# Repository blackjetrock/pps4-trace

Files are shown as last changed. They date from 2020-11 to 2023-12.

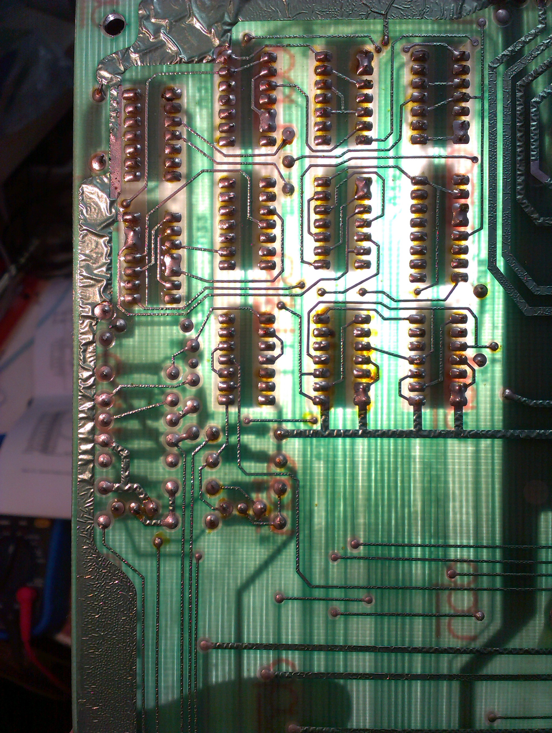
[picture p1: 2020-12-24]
schematics/IMAG7078.jpg

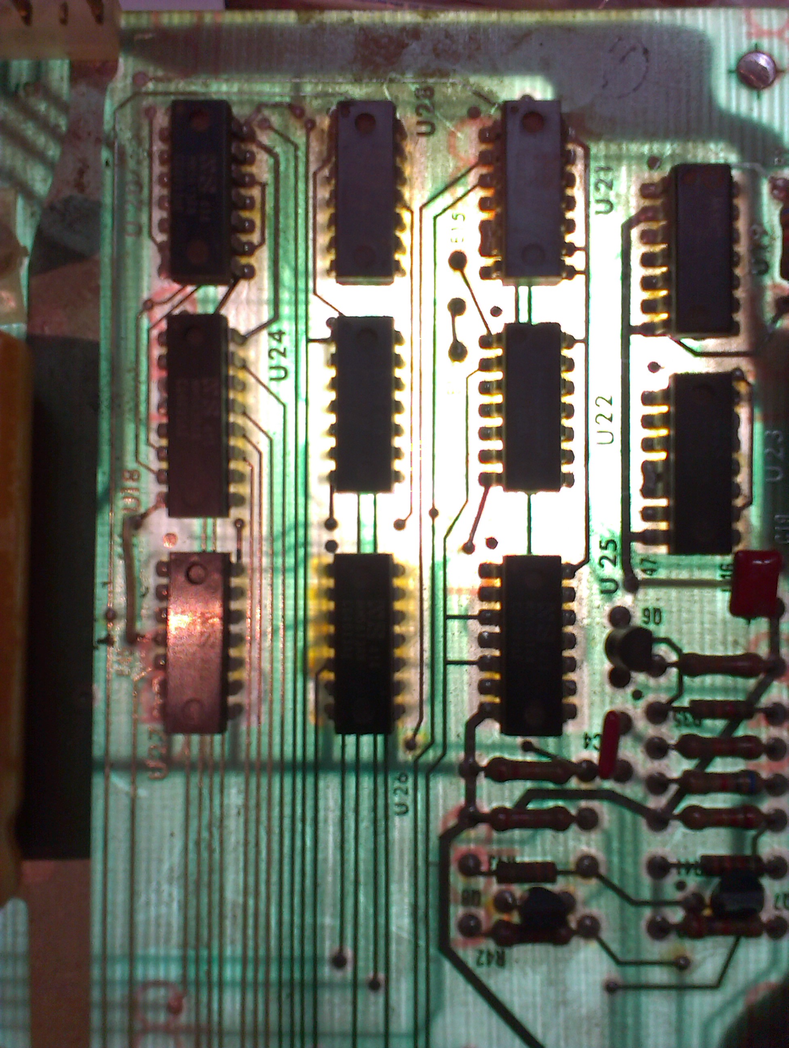
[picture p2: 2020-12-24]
schematics/IMAG7074.jpg

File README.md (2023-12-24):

# pps4-trace

Circuit to attempt to trace the address and data busses of the PPS-4 processor. the aim is to capture the ROM contents by sniffing the bus.
PPS-4 runs on -17V so circuit sits on 0V to -17v and divides down the inputs to 3V3.
PSU runs off PPS-4 supply

There's a few ROM image files I've managed to capture.

Although the bus tracing worked, it was difficult to work out exactly which ROM was bank switched and when. I therefore built a ROM dumper, desoldered a set of ROMs from a 920 and dumped them. This gave me the bank switching regime as the ROMs only responded to certain addressing. These ROMs were concatenated, effectively, and can be run in the simulator.
Details of the bank switching are in the simulator ROM file.

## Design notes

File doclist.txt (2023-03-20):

Part numbers of documents

Wanted

Programmer's Reference Manual        P/N 29001N20
Programmers' Ref Manual Supp No 1    P/N 29001N21

Already got copy

PPS-4 Basic devices Data Sheet       29003N11
PPS-4 Basic devices Supplement       2519-D-13
Bus Interface Circuit                10738N11

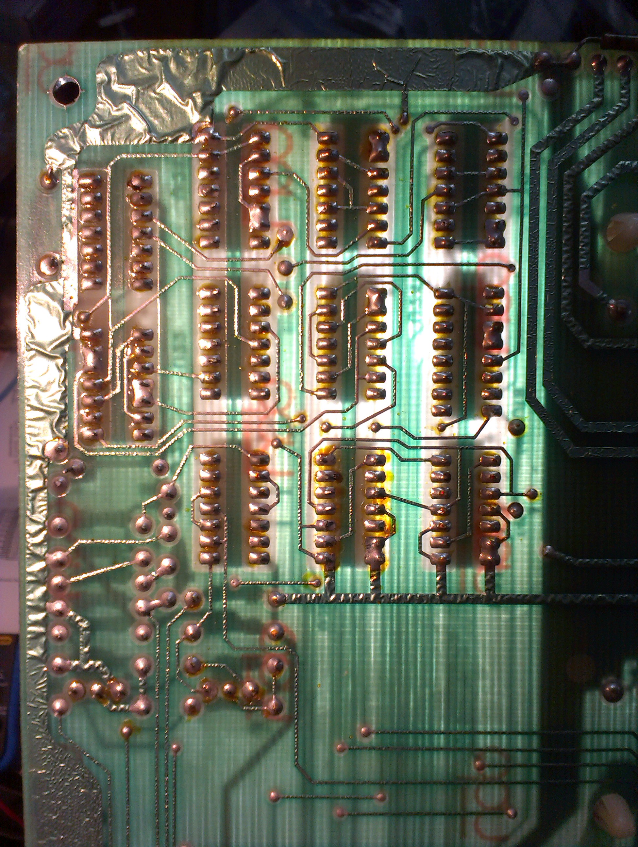
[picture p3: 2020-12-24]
schematics/IMAG7080.jpg

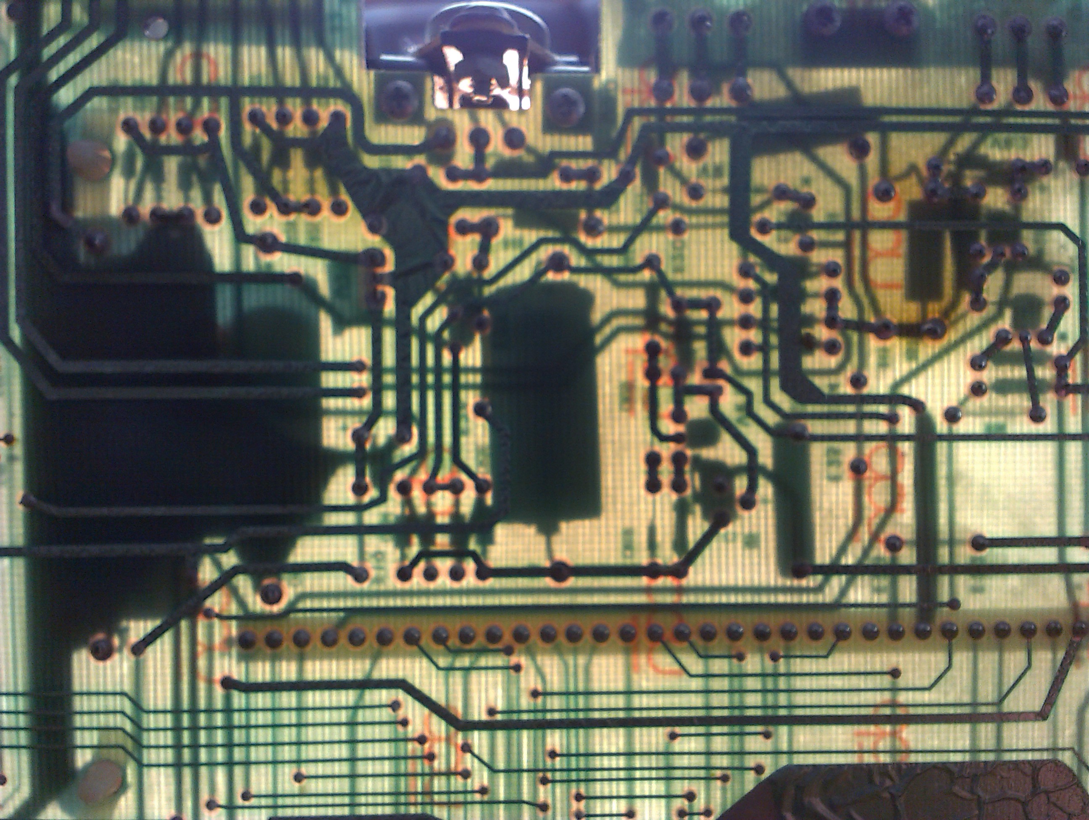
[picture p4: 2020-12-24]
schematics/IMAG7090.jpg

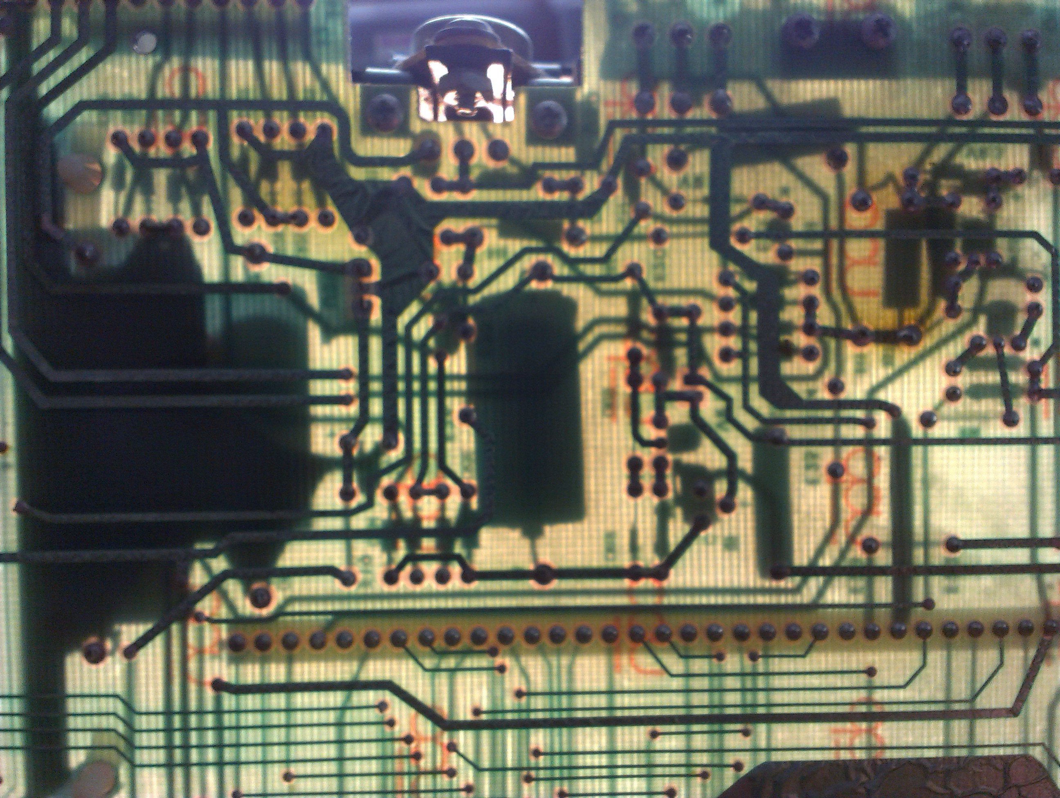
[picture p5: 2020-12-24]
schematics/IMAG7091.jpg

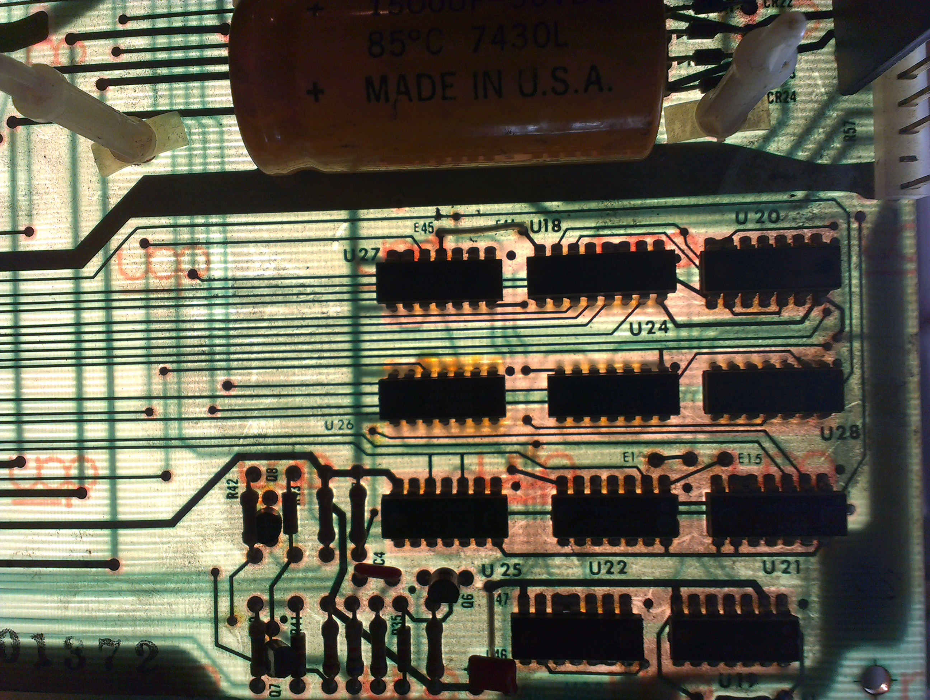
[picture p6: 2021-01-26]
schematics/IMAG7086.jpg

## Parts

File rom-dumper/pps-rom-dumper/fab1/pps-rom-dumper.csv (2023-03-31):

Id | Designator | Package | Quantity | Designation | Supplier and ref
1 | C6,C5,C4 | C_1210_3225Metric_Pad1.33x2.70mm_HandSolder | 3 | 100nF
2 | J1 | PinHeader_1x03_P2.54mm_Vertical | 1 | Conn_01x03_Female
3 | U3 | SOT-23-6 | 1 | Regulator_Switching_MT3608
4 | R36 | R_0805_2012Metric | 1 | 1500
5 | R35 | R_0805_2012Metric | 1 | 220
6 | R34 | R_0805_2012Metric | 1 | 47k
7 | L1 | L_Coilcraft_LPS5030 | 1 | 22uH
8 | JP2 | SolderJumper-2_P1.3mm_Open_Pad0.8x0.8mm | 1 | SolderJumper_2_Open
9 | JP1 | SolderJumper-2_P1.3mm_Open_Pad0.8x0.8mm | 1 | Jumper_NO_Small
10 | D1 | D_SOD-123 | 1 | SS36
11 | C3 | C_1210_3225Metric_Pad1.33x2.70mm_HandSolder | 1 | 10uF
12 | C2,C1 | C_1210_3225Metric_Pad1.33x2.70mm_HandSolder | 2 | 22uF
13 | U2 | qip42 | 1 | pps4-rom-a05
14 | U1 | RPi_Pico_SMD_TH | 1 | Pico
15 | R33,R32,R31,R30,R28,R26,R24,R22,R20,R18,R16,R14,R13,R12,R11,R10,R9,R8,R7,R6,R5,R4,R3,R2,R1 | R_0805_2012Metric_Pad1.20x1.40mm_HandSolder | 25 | 47k
16 | R29,R27,R25,R23,R21,R19,R17,R15 | R_0805_2012Metric_Pad1.20x1.40mm_HandSolder | 8 | 10k
17 | TR17,TR16,TR15,TR14,TR13,TR12,TR11,TR10,TR9,TR8,TR7,TR6,TR5,TR4,TR3,TR2,TR1 | SOT-23 | 17 | Si2302CDS-n-channel

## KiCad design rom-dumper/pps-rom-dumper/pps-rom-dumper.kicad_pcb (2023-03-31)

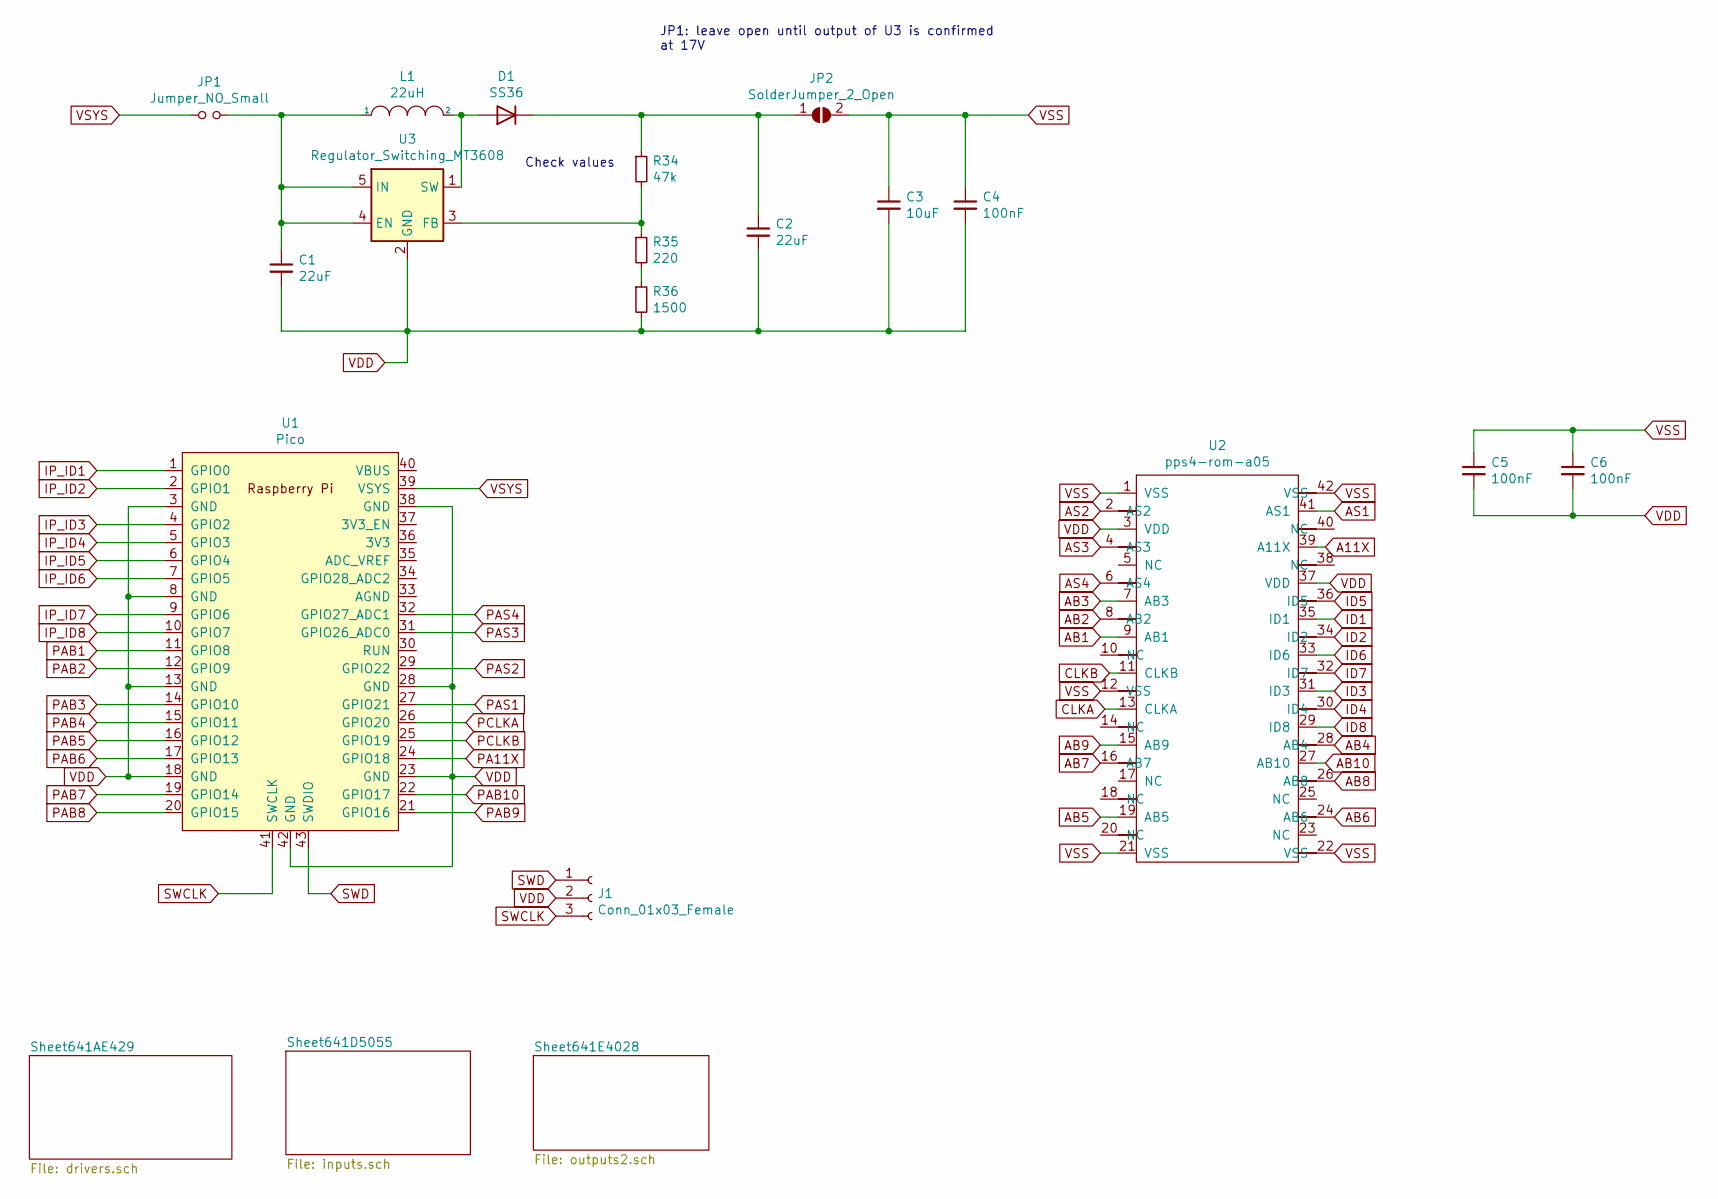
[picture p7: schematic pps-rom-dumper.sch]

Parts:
C1, C2: 22uF; C_1210_3225Metric_Pad1.33x2.70mm_HandSolder
C3: 10uF; C_1210_3225Metric_Pad1.33x2.70mm_HandSolder
C4, C5, C6: 100nF; C_1210_3225Metric_Pad1.33x2.70mm_HandSolder
D1: SS36; D_SOD-123
J1: Conn_01x03_Female; PinHeader_1x03_P2.54mm_Vertical
JP1: Jumper_NO_Small; SolderJumper-2_P1.3mm_Open_Pad0.8x0.8mm
JP2: SolderJumper_2_Open; SolderJumper-2_P1.3mm_Open_Pad0.8x0.8mm
L1: 22uH; L_Coilcraft_LPS5030
R34: 47k; R_0805_2012Metric
R35: 220; R_0805_2012Metric
R36: 1500; R_0805_2012Metric
U1: Pico; RPi_Pico_SMD_TH
U2: pps4-rom-a05; qip42
U3: Regulator_Switching_MT3608; SOT-23-6

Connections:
A11X: U2.39 (A11X); also elsewhere on the board
AB1: U2.9 (AB1); also elsewhere on the board
AB2: U2.8 (AB2); also elsewhere on the board
AB3: U2.7 (AB3); also elsewhere on the board
AB4: U2.28 (AB4); also elsewhere on the board
AB5: U2.19 (AB5); also elsewhere on the board
AB6: U2.24 (AB6); also elsewhere on the board
AB7: U2.16 (AB7); also elsewhere on the board
AB8: U2.26 (AB8); also elsewhere on the board
AB9: U2.15 (AB9); also elsewhere on the board
AB10: U2.27 (AB10); also elsewhere on the board
AS1: U2.41 (AS1); also elsewhere on the board
AS2: U2.2 (AS2); also elsewhere on the board
AS3: U2.4 (AS3); also elsewhere on the board
AS4: U2.6 (AS4); also elsewhere on the board
CLKA: U2.13 (CLKA); also elsewhere on the board
CLKB: U2.11 (CLKB); also elsewhere on the board
ID1: U2.35 (ID1); also elsewhere on the board
ID2: U2.34 (ID2); also elsewhere on the board
ID3: U2.31 (ID3); also elsewhere on the board
ID4: U2.30 (ID4); also elsewhere on the board
ID5: U2.36 (ID5); also elsewhere on the board
ID6: U2.33 (ID6); also elsewhere on the board
ID7: U2.32 (ID7); also elsewhere on the board
ID8: U2.29 (ID8); also elsewhere on the board
IP_ID1: U1.1 (GPIO0); also elsewhere on the board
IP_ID2: U1.2 (GPIO1); also elsewhere on the board
IP_ID3: U1.4 (GPIO2); also elsewhere on the board
IP_ID4: U1.5 (GPIO3); also elsewhere on the board
IP_ID5: U1.6 (GPIO4); also elsewhere on the board
IP_ID6: U1.7 (GPIO5); also elsewhere on the board
IP_ID7: U1.9 (GPIO6); also elsewhere on the board
IP_ID8: U1.10 (GPIO7); also elsewhere on the board
unnamed: C1.1, JP1.2, L1.1, U3.4 (EN), U3.5 (IN)
unnamed: C2.1, D1.1 (K), JP2.1 (A), R34.1
unnamed: D1.2 (A), L1.2, U3.1 (SW)
unnamed: R34.2, R35.1, U3.3 (FB)
unnamed: R35.2, R36.1
PA11X: U1.24 (GPIO18)
PAB1: U1.11 (GPIO8); also elsewhere on the board
PAB2: U1.12 (GPIO9); also elsewhere on the board
PAB3: U1.14 (GPIO10); also elsewhere on the board
PAB4: U1.15 (GPIO11); also elsewhere on the board
PAB5: U1.16 (GPIO12); also elsewhere on the board
PAB6: U1.17 (GPIO13); also elsewhere on the board
PAB7: U1.19 (GPIO14); also elsewhere on the board
PAB8: U1.20 (GPIO15); also elsewhere on the board
PAB9: U1.21 (GPIO16); also elsewhere on the board
PAB10: U1.22 (GPIO17); also elsewhere on the board
PAS1: U1.27 (GPIO21); also elsewhere on the board
PAS2: U1.29 (GPIO22); also elsewhere on the board
PAS3: U1.31 (GPIO26_ADC0); also elsewhere on the board
PAS4: U1.32 (GPIO27_ADC1); also elsewhere on the board
PCLKA: U1.26 (GPIO20); also elsewhere on the board
PCLKB: U1.25 (GPIO19); also elsewhere on the board
SWCLK: J1.3, U1.41 (SWCLK)
SWD: J1.1, U1.43 (SWDIO)
VDD: C1.2, C2.2, C3.2, C4.2, C5.2, C6.2, J1.2, R36.2, U1.3 (GND), U1.8 (GND), U1.13 (GND), U1.18 (GND), U1.23 (GND), U1.28 (GND), U1.38 (GND), U1.42 (GND), U2.3 (VDD), U2.37 (VDD), U3.2 (GND); also elsewhere on the board
VSS: C3.1, C4.1, C5.1, C6.1, JP2.2 (B), U2.1 (VSS), U2.12 (VSS), U2.21 (VSS), U2.22 (VSS), U2.42 (VSS); also elsewhere on the board
VSYS: JP1.1, U1.39 (VSYS)

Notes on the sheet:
Check values
JP1: leave open until output of U3 is confirmed at 17V

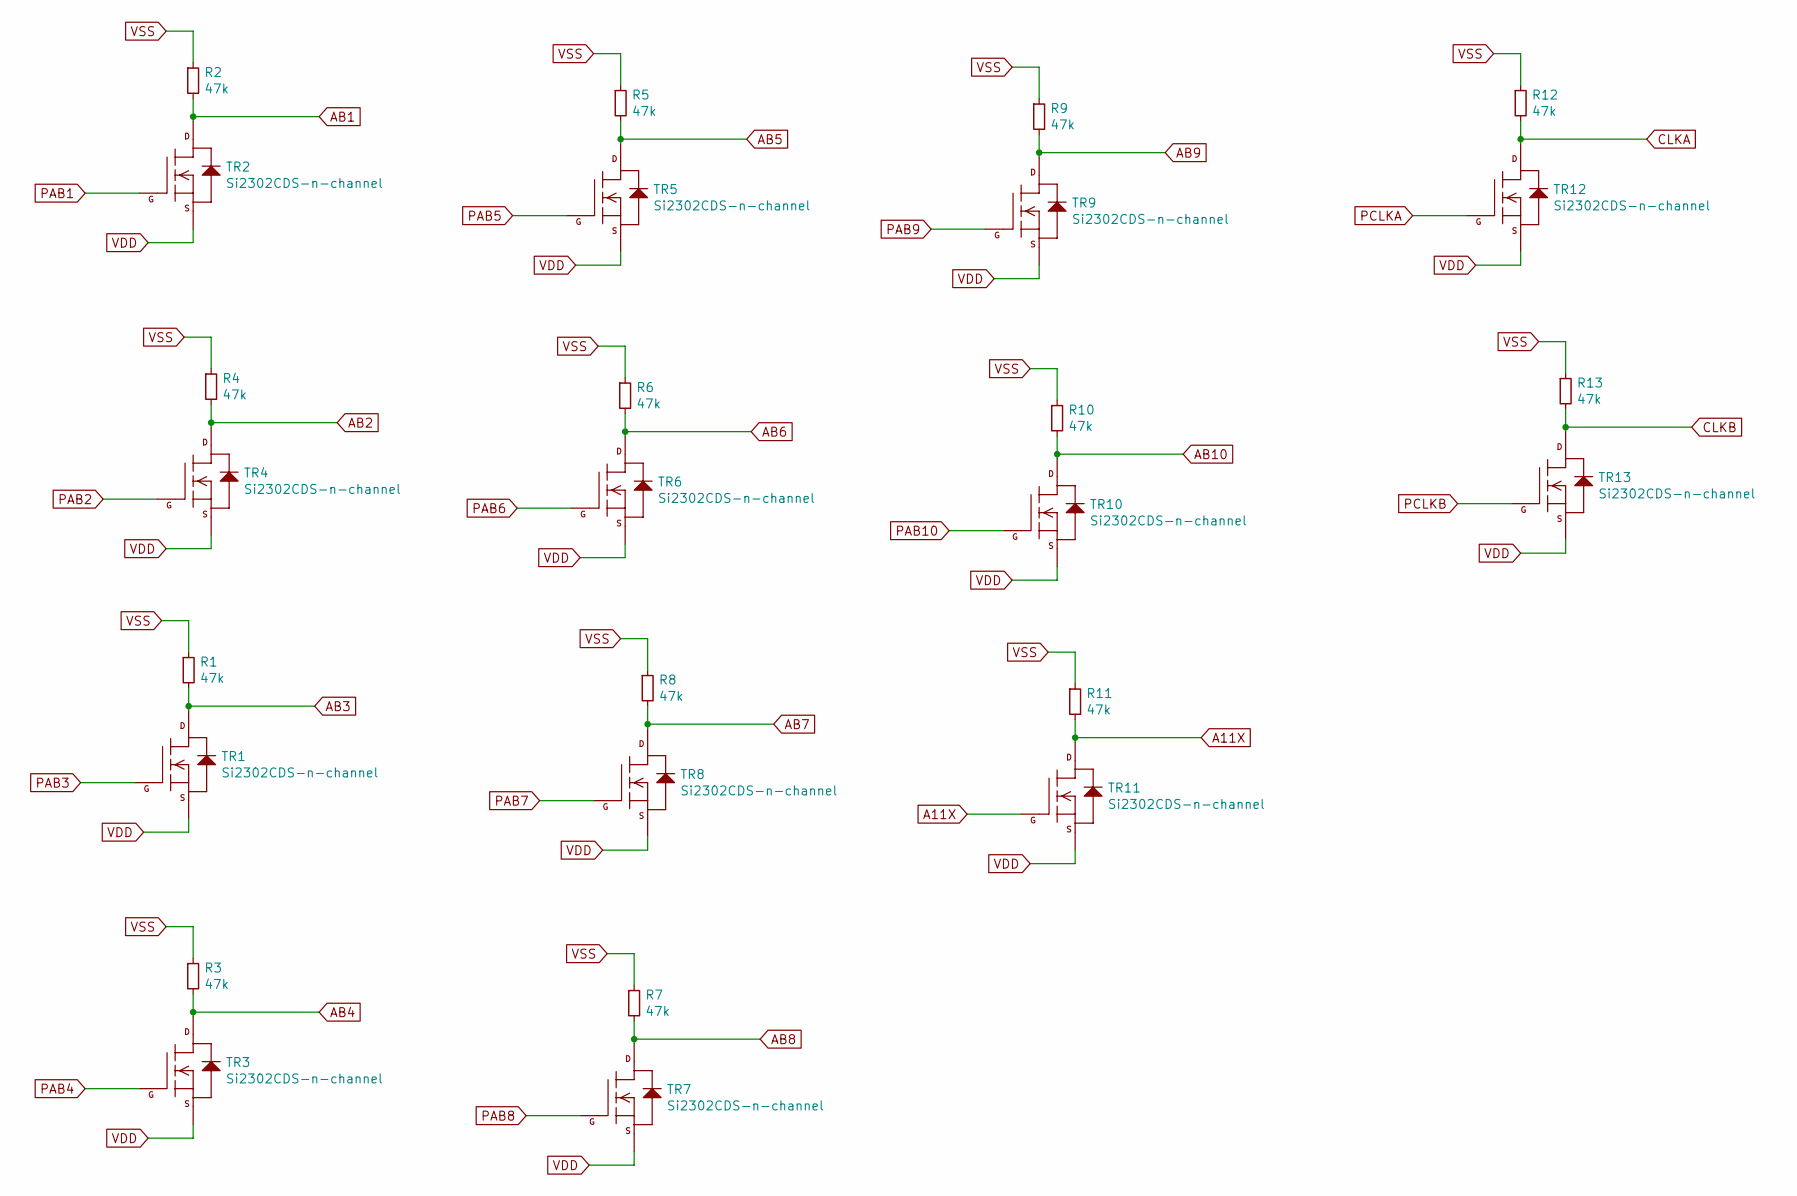
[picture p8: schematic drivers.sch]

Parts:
R1, R2, R3, R4, R5, R6, R7, R8, R9, R10, R11, R12, R13: 47k; R_0805_2012Metric_Pad1.20x1.40mm_HandSolder
TR1, TR2, TR3, TR4, TR5, TR6, TR7, TR8, TR9, TR10, TR11, TR12, TR13: Si2302CDS-n-channel; SOT-23

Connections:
A11X: R11.2, TR11.1 (G), TR11.3 (D); also elsewhere on the board
AB1: R2.2, TR2.3 (D); also elsewhere on the board
AB2: R4.2, TR4.3 (D); also elsewhere on the board
AB3: R1.2, TR1.3 (D); also elsewhere on the board
AB4: R3.2, TR3.3 (D); also elsewhere on the board
AB5: R5.2, TR5.3 (D); also elsewhere on the board
AB6: R6.2, TR6.3 (D); also elsewhere on the board
AB7: R8.2, TR8.3 (D); also elsewhere on the board
AB8: R7.2, TR7.3 (D); also elsewhere on the board
AB9: R9.2, TR9.3 (D); also elsewhere on the board
AB10: R10.2, TR10.3 (D); also elsewhere on the board
CLKA: R12.2, TR12.3 (D); also elsewhere on the board
CLKB: R13.2, TR13.3 (D); also elsewhere on the board
PAB1: TR2.1 (G); also elsewhere on the board
PAB2: TR4.1 (G); also elsewhere on the board
PAB3: TR1.1 (G); also elsewhere on the board
PAB4: TR3.1 (G); also elsewhere on the board
PAB5: TR5.1 (G); also elsewhere on the board
PAB6: TR6.1 (G); also elsewhere on the board
PAB7: TR8.1 (G); also elsewhere on the board
PAB8: TR7.1 (G); also elsewhere on the board
PAB9: TR9.1 (G); also elsewhere on the board
PAB10: TR10.1 (G); also elsewhere on the board
PCLKA: TR12.1 (G); also elsewhere on the board
PCLKB: TR13.1 (G); also elsewhere on the board
VDD: TR1.2 (S), TR2.2 (S), TR3.2 (S), TR4.2 (S), TR5.2 (S), TR6.2 (S), TR7.2 (S), TR8.2 (S), TR9.2 (S), TR10.2 (S), TR11.2 (S), TR12.2 (S), TR13.2 (S); also elsewhere on the board
VSS: R1.1, R2.1, R3.1, R4.1, R5.1, R6.1, R7.1, R8.1, R9.1, R10.1, R11.1, R12.1, R13.1; also elsewhere on the board

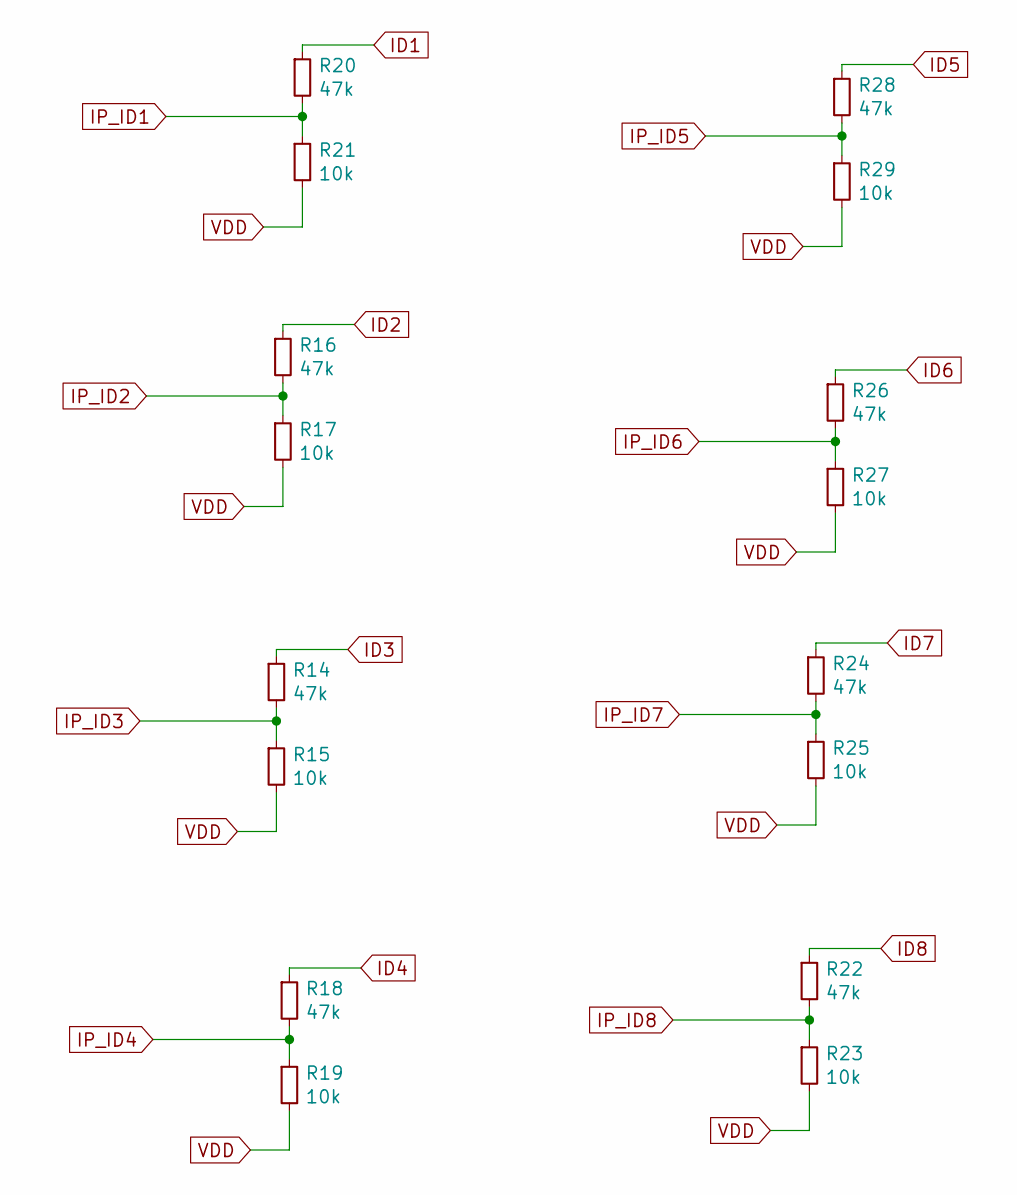
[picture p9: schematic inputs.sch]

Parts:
R14, R16, R18, R20, R22, R24, R26, R28: 47k; R_0805_2012Metric_Pad1.20x1.40mm_HandSolder
R15, R17, R19, R21, R23, R25, R27, R29: 10k; R_0805_2012Metric_Pad1.20x1.40mm_HandSolder

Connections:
ID1: R20.1; also elsewhere on the board
ID2: R16.1; also elsewhere on the board
ID3: R14.1; also elsewhere on the board
ID4: R18.1; also elsewhere on the board
ID5: R28.1; also elsewhere on the board
ID6: R26.1; also elsewhere on the board
ID7: R24.1; also elsewhere on the board
ID8: R22.1; also elsewhere on the board
IP_ID1: R20.2, R21.1; also elsewhere on the board
IP_ID2: R16.2, R17.1; also elsewhere on the board
IP_ID3: R14.2, R15.1; also elsewhere on the board
IP_ID4: R18.2, R19.1; also elsewhere on the board
IP_ID5: R28.2, R29.1; also elsewhere on the board
IP_ID6: R26.2, R27.1; also elsewhere on the board
IP_ID7: R24.2, R25.1; also elsewhere on the board
IP_ID8: R22.2, R23.1; also elsewhere on the board
VDD: R15.2, R17.2, R19.2, R21.2, R23.2, R25.2, R27.2, R29.2; also elsewhere on the board

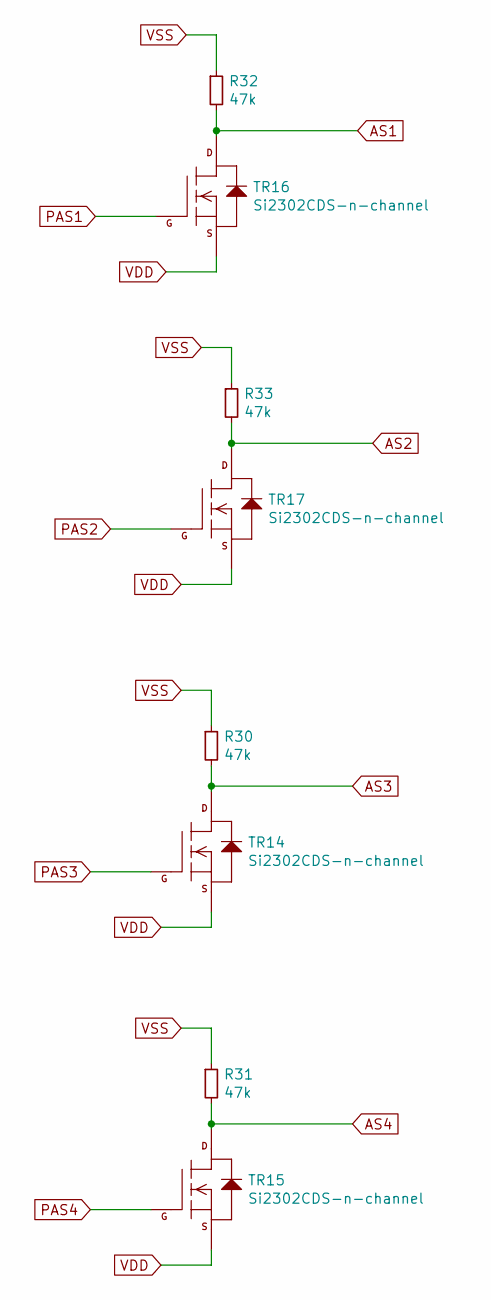
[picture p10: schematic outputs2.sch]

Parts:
R30, R31, R32, R33: 47k; R_0805_2012Metric_Pad1.20x1.40mm_HandSolder
TR14, TR15, TR16, TR17: Si2302CDS-n-channel; SOT-23

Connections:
AS1: R32.2, TR16.3 (D); also elsewhere on the board
AS2: R33.2, TR17.3 (D); also elsewhere on the board
AS3: R30.2, TR14.3 (D); also elsewhere on the board
AS4: R31.2, TR15.3 (D); also elsewhere on the board
PAS1: TR16.1 (G); also elsewhere on the board
PAS2: TR17.1 (G); also elsewhere on the board
PAS3: TR14.1 (G); also elsewhere on the board
PAS4: TR15.1 (G); also elsewhere on the board
VDD: TR14.2 (S), TR15.2 (S), TR16.2 (S), TR17.2 (S); also elsewhere on the board
VSS: R30.1, R31.1, R32.1, R33.1; also elsewhere on the board

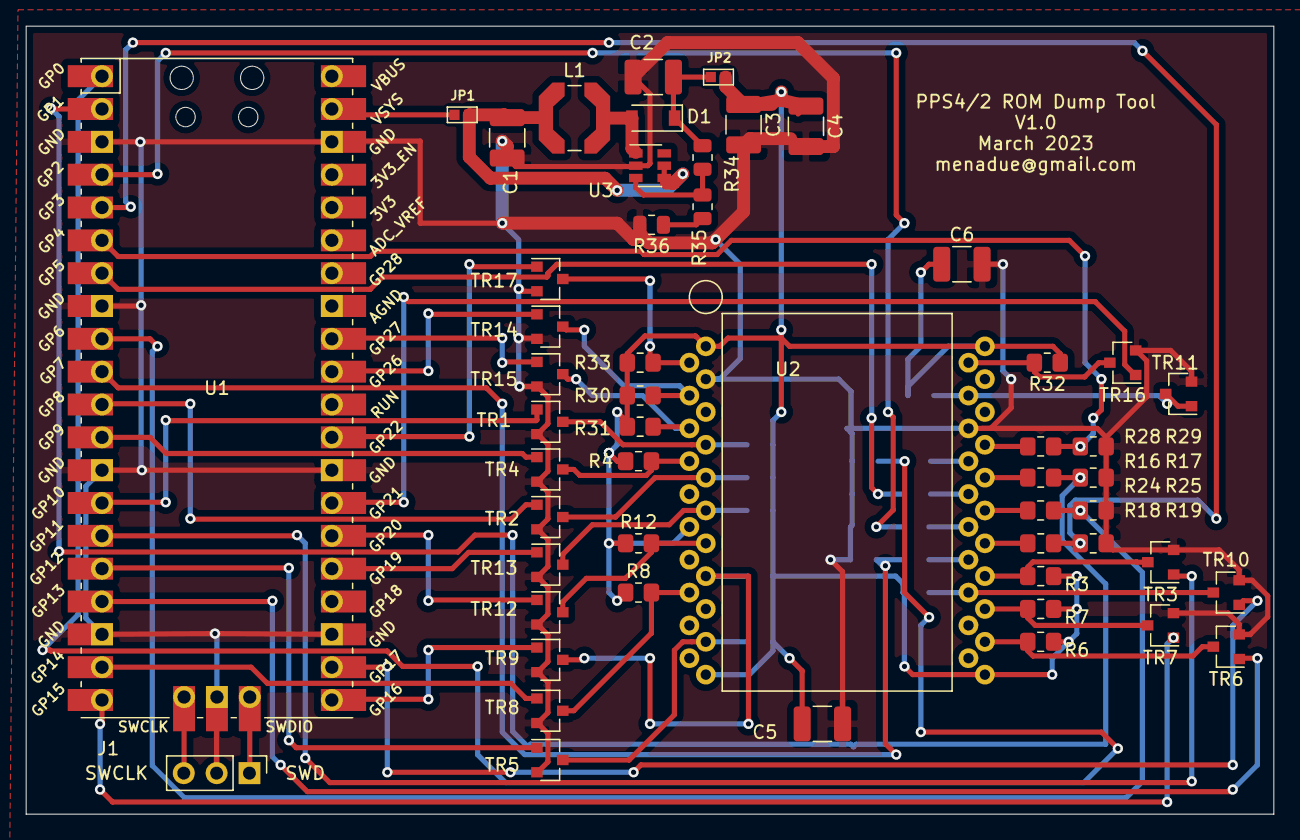
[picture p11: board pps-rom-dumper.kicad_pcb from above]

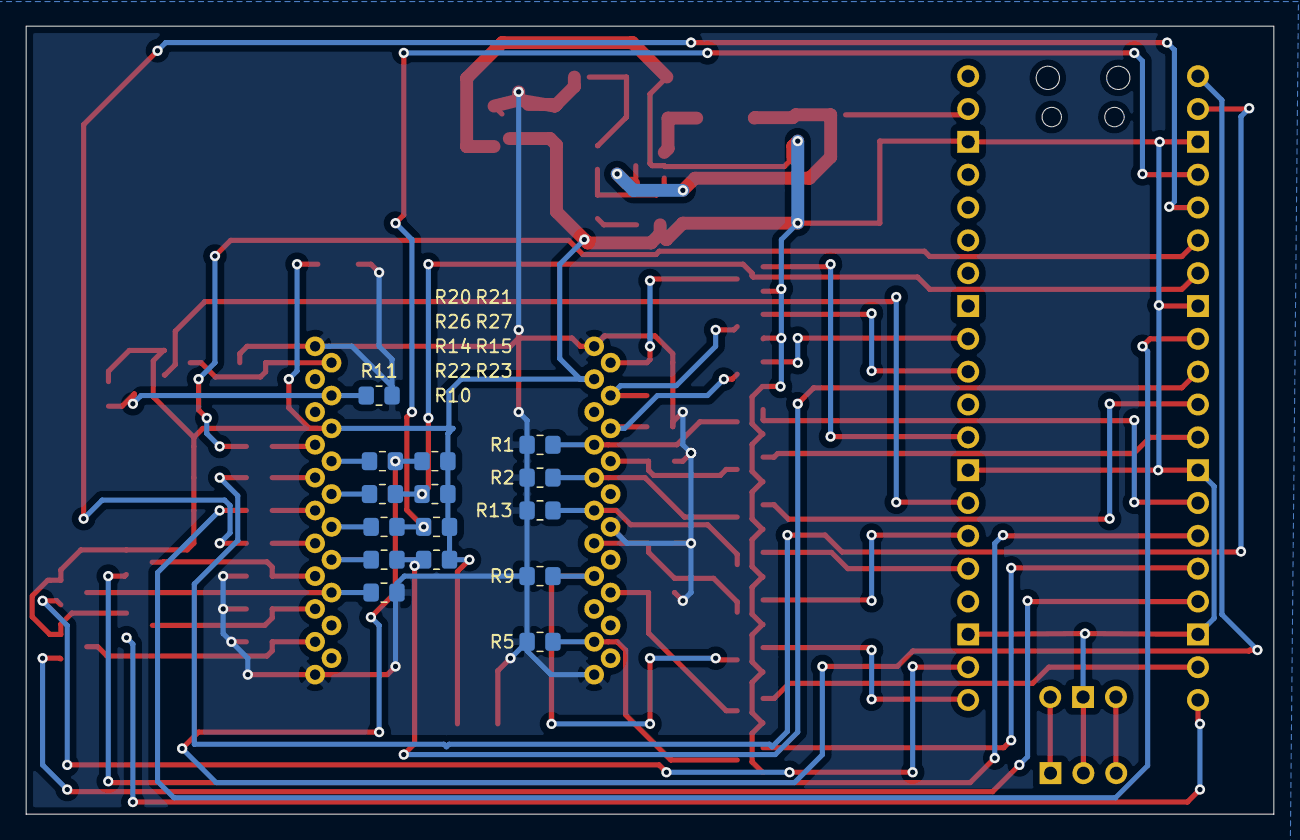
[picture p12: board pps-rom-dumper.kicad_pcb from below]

Board: 2 copper layers, 96.5 x 61.0 mm, 67 parts (15 on the bottom side), 59 nets.

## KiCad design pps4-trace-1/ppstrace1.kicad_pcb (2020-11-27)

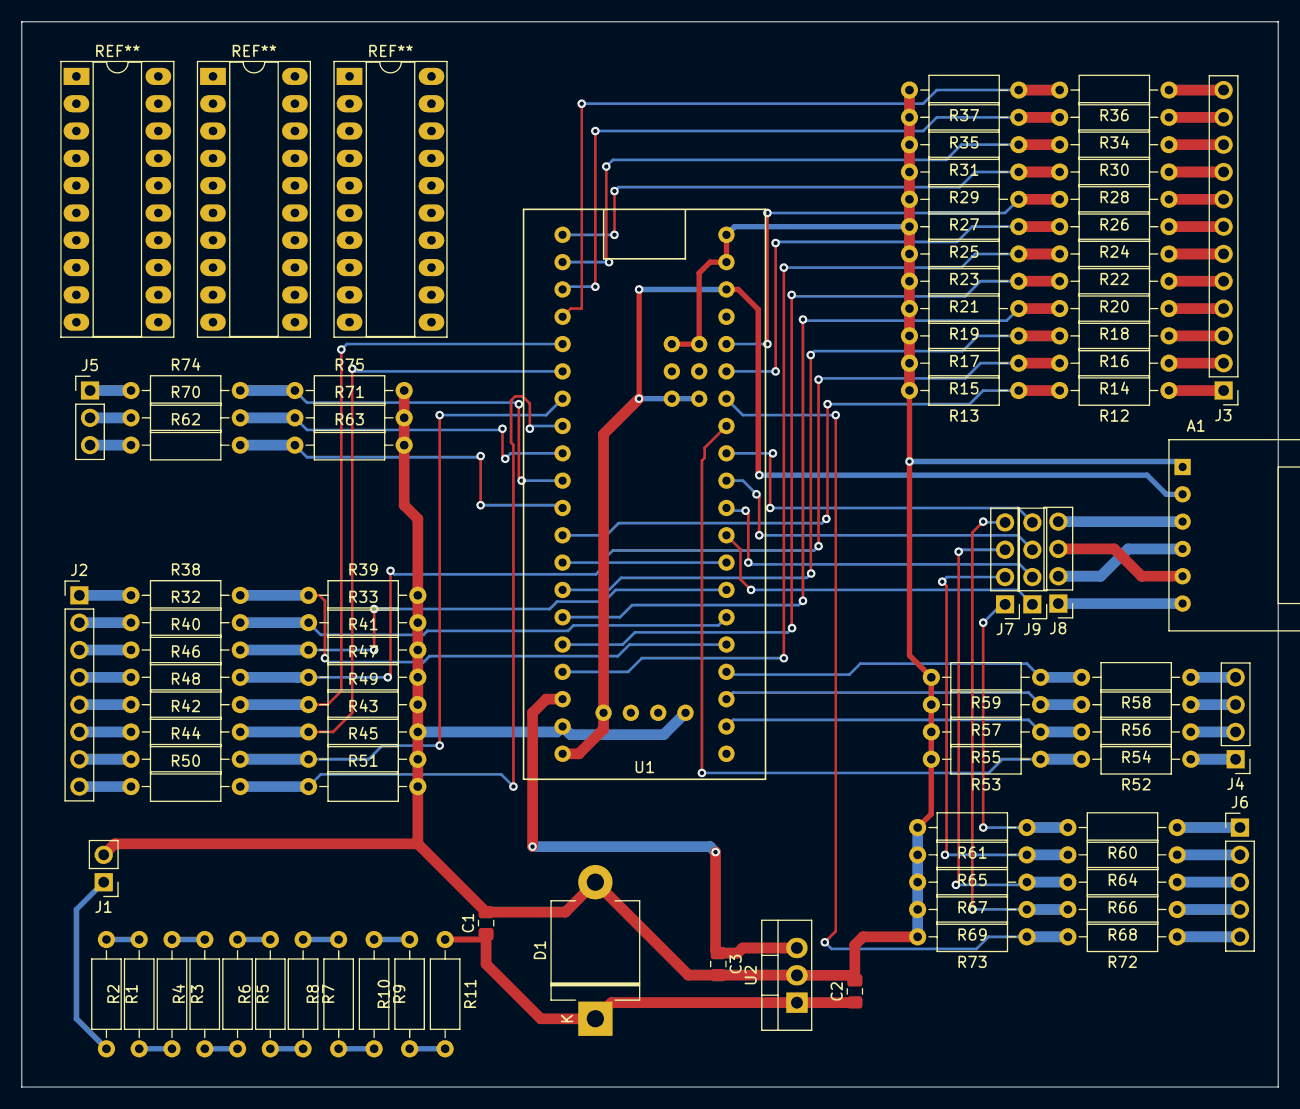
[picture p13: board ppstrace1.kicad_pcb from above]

Board: 2 copper layers, 116.8 x 99.1 mm, 91 parts (0 on the bottom side), 87 nets.

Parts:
A1: SD_Card_Module_catalex; SD_Card_Module
C1, C2, C3: C_Small; C_0805_2012Metric_Pad1.15x1.40mm_HandSolder
D1: D_Zener; D_5KPW_P12.70mm_Horizontal
J1: Conn_01x02_Male; PinHeader_1x02_P2.54mm_Vertical
J2: Conn_01x08_Male; PinHeader_1x08_P2.54mm_Vertical
J3: Conn_01x12_Male; PinHeader_1x12_P2.54mm_Vertical
J4, J7, J8, J9: Conn_01x04_Male; PinHeader_1x04_P2.54mm_Vertical
J5: Conn_01x03_Male; PinHeader_1x03_P2.54mm_Vertical
J6: Conn_01x05_Male; PinHeader_1x05_P2.54mm_Vertical
R1, R2, R3, R4, R5, R6, R7, R8, R9, R10: 10R; R_Axial_DIN0207_L6.3mm_D2.5mm_P10.16mm_Horizontal
R11: R_Small; R_Axial_DIN0207_L6.3mm_D2.5mm_P10.16mm_Horizontal
R12, R14, R16, R18, R20, R22, R24, R26, R28, R30, R32, R34, R36, R38, R40, R42, R44, R46, R48, R50, R52, R54, R56, R58, R60, R62, R64, R66, R68, R70, R72, R74: 10k; R_Axial_DIN0207_L6.3mm_D2.5mm_P10.16mm_Horizontal
R13, R15, R17, R19, R21, R23, R25, R27, R29, R31, R33, R35, R37, R39, R41, R43, R45, R47, R49, R51, R53, R55, R57, R59, R61, R63, R65, R67, R69, R71, R73, R75: 2k2; R_Axial_DIN0207_L6.3mm_D2.5mm_P10.16mm_Horizontal
U1: BP; BLUEPILL
U2: LM7805_TO220; TO-220-3_Vertical

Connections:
+3V3: A1.2, U1.3V3
+5V: C3.1, U1.5V, U2.3
A1: J3.1, R12.1
A2: J3.2, R14.1
A3: J3.3, R16.1
A4: J3.4, R18.1
A5: J3.5, R20.1
A6: J3.6, R22.1
A7: J3.7, R24.1
A8: J3.8, R26.1
A9: J3.9, R28.1
A10: J3.10, R30.1
A11: J3.11, R34.1
A12: J3.12, R36.1
CLKA: J5.1, R74.1
CLKB: J5.2, R70.1
D1: J2.1, R38.1
D2: J2.2, R32.1
D3: J2.3, R40.1
D4: J2.4, R46.1
D5: J2.5, R48.1
D6: J2.6, R42.1
D7: J2.7, R44.1
D8: J2.8, R50.1
DO1: J4.1, R52.1
DO2: J4.2, R54.1
DO3: J4.3, R56.1
DO4: J4.4, R58.1
GND: A1.1, C1.2, C2.2, C3.2, D1.2, J1.2, R13.2, R15.2, R17.2, R19.2, R21.2, R23.2, R25.2, R27.2, R29.2, R31.2, R33.2, R35.2, R37.2, R39.2, R41.2, R43.2, R45.2, R47.2, R49.2, R51.2, R53.2, R55.2, R57.2, R59.2, R61.2, R63.2, R65.2, R67.2, R69.2, R71.2, R73.2, R75.2, U1.G, U2.2
IA1: R12.2, R13.1, U1.PB4
IA2: R14.2, R15.1, U1.PB5
IA3: R16.2, R17.1, U1.PB6
IA4: R18.2, R19.1, U1.PB7
IA5: R20.2, R21.1, U1.PB8
IA6: R22.2, R23.1, U1.PB9
IA7: R24.2, R25.1, U1.PB10
IA8: R26.2, R27.1, U1.PB11
IA9: R28.2, R29.1, U1.PB12
IA10: R30.2, R31.1, U1.PB13
IA11: R34.2, R35.1, U1.PB14
IA12: R36.2, R37.1, U1.PB15
ICLKA: R74.2, R75.1, U1.PA15
ICLKB: R70.2, R71.1, U1.PA12
ID1: R38.2, R39.1, U1.PA0
ID2: R32.2, R33.1, U1.PA1
ID3: R40.2, R41.1, U1.PA2
ID4: R46.2, R47.1, U1.PA3
ID5: R48.2, R49.1, U1.PA8
ID6: R42.2, R43.1, U1.PA9
ID7: R44.2, R45.1, U1.PA10
ID8: R50.2, R51.1, U1.PA11
IDO1: R52.2, R53.1, U1.PB0
IDO2: R54.2, R55.1, U1.PC13
IDO3: R56.2, R57.1, U1.PC14
IDO4: R58.2, R59.1, U1.PC15
IWIO: R62.2, R63.1, U1.PB3
IX1: J7.1, R60.2, R61.1
IX2: J7.2, R64.2, R65.1
IX3: J7.3, R66.2, R67.1
IX4: J7.4, R68.2, R69.1
IX5: R72.2, R73.1, U1.PB1
unnamed: A1.3, J8.4
unnamed: A1.4, J8.2
unnamed: A1.5, J8.3
unnamed: A1.6, J8.1
unnamed: C1.1, C2.1, D1.1, R11.1, U2.1
unnamed: J1.1, R1.2
unnamed: J9.1, U1.PA4
unnamed: J9.2, U1.PA5
unnamed: J9.3, U1.PA6
unnamed: J9.4, U1.PA7
unnamed: R1.1, R2.2
unnamed: R2.1, R3.2
unnamed: R3.1, R4.2
unnamed: R4.1, R5.2
unnamed: R5.1, R6.2
unnamed: R6.1, R7.2
unnamed: R7.1, R8.2
unnamed: R8.1, R9.2
unnamed: R10.1, R11.2
unnamed: R9.1, R10.2
WIO: J5.3, R62.1
X1: J6.1, R60.1
X2: J6.2, R64.1
X3: J6.3, R66.1
X4: J6.4, R68.1
X5: J6.5, R72.1

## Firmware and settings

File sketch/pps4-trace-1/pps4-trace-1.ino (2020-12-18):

//
// Bus trace capture for Rockwell PPS4 processor
//

const int IDO1Pin = PB0;
const int IDO2Pin = PC13;
const int IDO3Pin = PC14;
const int IDO4Pin = PC15;

const int ID1Pin = PA0;
const int ID2Pin = PA1;
const int ID3Pin = PA2;
const int ID4Pin = PA3;
const int ID5Pin = PA8;
const int ID6Pin = PA9;
const int ID7Pin = PA10;
const int ID8Pin = PB1;    /* rewired */

const int IA1Pin  = PB4;
const int IA2Pin  = PB5;
const int IA3Pin  = PB6;
const int IA4Pin  = PB7;
const int IA5Pin  = PB8;
const int IA6Pin  = PB9;
const int IA7Pin  = PB10;
const int IA8Pin  = PB11;
const int IA9Pin  = PB12;
const int IA10Pin = PB13;
const int IA11Pin = PB14;
const int IA12Pin = PB15;

const int IWIOPin  = PA15;
const int ICLKAPin = PB3;
const int ICLKBPin = PA7;    /*  rewired */
const int POPin    = PA4;

#define PORT_A         (GPIOA->IDR)
#define PORT_B         (GPIOB->IDR)
#define PORT_C         (GPIOC->IDR)

#define NUM_SAMPLES  1000

uint16_t pa[NUM_SAMPLES];
uint16_t pb[NUM_SAMPLES];
uint16_t pc[NUM_SAMPLES];

// ROM data
#define ROM_SIZE 4096

uint8_t rom[ROM_SIZE];

void setup() {
  int i;
  
  // Set serial port up
  delay(500);
  Serial.begin(2000000);
  delay(500);

  Serial.println("PPS4 Tracer");
  delay(1000);
  Serial.println("PPS4 Tracer");
  delay(1000);
  Serial.println("PPS4 Tracer");
  delay(1000);
  Serial.println("PPS4 Tracer");
  delay(1000);

  pinMode(IDO1Pin, INPUT);
  pinMode(IDO2Pin, INPUT);
  pinMode(IDO3Pin, INPUT);
  pinMode(IDO4Pin, INPUT);

  pinMode(ID1Pin, INPUT);
  pinMode(ID2Pin, INPUT);
  pinMode(ID3Pin, INPUT);
  pinMode(ID4Pin, INPUT);
  pinMode(ID5Pin, INPUT);
  pinMode(ID6Pin, INPUT);
  pinMode(ID7Pin, INPUT);
  pinMode(ID8Pin, INPUT);

  pinMode(IA1Pin, INPUT);
  pinMode(IA2Pin, INPUT);
  pinMode(IA3Pin, INPUT);
  pinMode(IA4Pin, INPUT);
  pinMode(IA5Pin, INPUT);
  pinMode(IA6Pin, INPUT);
  pinMode(IA7Pin, INPUT);
  pinMode(IA8Pin, INPUT);
  pinMode(IA9Pin, INPUT);
  pinMode(IA10Pin, INPUT);
  pinMode(IA11Pin, INPUT);
  pinMode(IA12Pin, INPUT);

  pinMode(IWIOPin, INPUT);
  pinMode(ICLKAPin, INPUT);
  pinMode(ICLKBPin, INPUT);
  pinMode(POPin,    INPUT);
  
}
int last_po=0;
int po_count = 0;
int reset_threshold = 200;

void loop() {
  boolean donecap = false;
  
  int i;
  char c;
  int clkb = 0x80;
  int done = 0;
  int clk_count = 0;
  int last_clk = 0;  
  int po;

  int addr, data, clka, last_clkb = -1;
  int phase_count, rom_addr;
  
  // Capture at reset, if we see a rising edge on
  // PO pin

#if 1
  pa[0] = PORT_A;
  po = (pa[0] & 0x10) >> 4;

  if( (po == 1) && (last_po == 0) )
    {
      po_count++;
      if( po_count == 1 )
	{
	  po_count = 0;

	  // reset has gone high, we wait for some clock
	  // cycles before capturing
	  clk_count = 0;
	  
	  while( !donecap )
	    {
	    pa[0] = PORT_A;
	    clkb = pa[0] & 0x80;
	    if( last_clk != clkb)
	      {
		clk_count++;

		if( clk_count > reset_threshold )
		  {
		    donecap = true;
		  }
	      }
	    last_clk = clkb;
	    
	    }
	  
	  for(i=0;i<NUM_SAMPLES;i++)
	    {
	      pa[i] = PORT_A;
	      pb[i] = PORT_B;
	      pc[i] = PORT_C;
	    }
	  
	  for(i=0;i<NUM_SAMPLES;i++)
	    {
	      //	  Serial.print(i);
	      Serial.print("A:");
	      Serial.print(pa[i], HEX);
	      Serial.print(" B:");
	      Serial.print(pb[i], HEX);
	      Serial.print(" C:");
	      Serial.println(pc[i], HEX);
	    }
	}
    }
  last_po = po;

#endif
  
  if( Serial.available() )
    {
      c = Serial.read();

      switch(c)
	{
	case '+':
	  reset_threshold +=100;
	  Serial.print("Reset threshold now ");
	  Serial.println(reset_threshold);
	  break;

	case '-':
	  reset_threshold -=100;
	  Serial.print("Reset threshold now ");
	  Serial.println(reset_threshold);
	  break;
	  
	case 'p':
	  for(i=0;i<NUM_SAMPLES;i++)
	    {
	      //	  Serial.print(i);
	      Serial.print("A:");
	      Serial.print(pa[i], HEX);
	      Serial.print(" B:");
	      Serial.print(pb[i], HEX);
	      Serial.print(" C:");
	      Serial.println(pc[i], HEX);
	    }
	  break;

	case 'k':
	  // Captures bursts of trace and dumps them out the serial
	  // port. 
	  //
	  // x to stop
	  Serial.println("Burst tracing...");
	  done = false;
	  
	  while( !done )
	    {
	      if( Serial.available() )
		{
		  c = Serial.read();

		  if( c == 'x' )
		    {
		      done = true;
		    }
		}

	      // Get a burst
	      for(i=0;i<NUM_SAMPLES;i++)
		{
		  pa[i] = PORT_A;
		  pb[i] = PORT_B;
		  pc[i] = PORT_C;
		}

	      // Dump it out the serial port
	      for(i=0;i<NUM_SAMPLES;i++)
		{
		  //	  Serial.print(i);
		  Serial.print("A:");
		  Serial.print(pa[i], HEX);
		  Serial.print(" B:");
		  Serial.print(pb[i], HEX);
		  Serial.print(" C:");
		  Serial.println(pc[i], HEX);
		}
	      
	    }
	  Serial.println("Stopped.");
	  break;

	case 'c':
	  // Captures and processes bursts continuously
	  // dumping ROM addresses and data out the serial port
	  //
	  // Captures data in rom array at rom addresses. Only handles
	  // 12 bit address range for now. Details of ROm chip addressing
	  // are not worked out. One may be a 'RAM' mask setting
	  //
	  // x to stop
	  Serial.println("Capturing...");
	  done = false;
	  
	  while( !done )
	    {
	      if( Serial.available() )
		{
		  c = Serial.read();

		  if( c == 'x' )
		    {
		      done = true;
		    }
		}
	      
	      for(i=0;i<NUM_SAMPLES;i++)
		{
		  pa[i] = PORT_A;
		  pb[i] = PORT_B;
		  pc[i] = PORT_C;
		}
	      
	      // Process
	      for(i=0;i<NUM_SAMPLES;i++)
		{
		  addr = pb[i] >> 4;
		  data = (pa[i] & 0xF) | ((pa[i] & 0x700) >> 4) | ((pb[i] & 0x02)<<6);
		  clka = (pb[i] & 0x8) >> 3;
		  clkb = (pa[i] & 0x80) >> 7;
		  
		  addr ^= 0xfff;
		  data ^= 0xff;
		  
#if 0
		  Serial.print("A:");
		  Serial.print(addr, HEX);
		  Serial.print(" ");
		  Serial.print(data, HEX);
		  Serial.print(" ");
		  Serial.print(phase_count);
		  Serial.println();
#endif
		  
		  if ( last_clkb != clkb )
		    {
		      phase_count = 0;
		    }
		  else
		    {
		      phase_count++;
		    }
		  
		  if ( (clka == 1) && (clkb == 0) && (phase_count == 1) )
		    {
		      // ROM value
		      // Dump address
#if 0		      
		      Serial.print(rom_addr,HEX);
		      Serial.print(":");
		      Serial.println(data, HEX);
#else
		      // Store in ROM image
		      rom[rom_addr] = data;		      
#endif
		    }
		  
		  if ( (clka == 0) && (clkb == 0) && (phase_count == 1) )
		    {
		      rom_addr = addr;
		    }
		  
		  last_clkb = clkb;
		}
	    }
	  Serial.println("Stopped.");
	  break;
	  
	case 'r':
	  //
	  // Dump ROM
	  // 
	  for(i=0; i<ROM_SIZE;i++)
	    {
	      Serial.print(rom[i],HEX);
	      Serial.print(" ");

	      if( (i%16) == 15 )
		{
		  Serial.println("");
		}
	    }
	  Serial.println("");
	  break;
	  
	case ' ':
	  // Capture a burst
#if 0
	  for(i=0;i<NUM_SAMPLES;i++)
	    {
	      // Wait for clock edge
	      pa[i] = PORT_A;
	      
	      while( (pa[i] & 0x80) == clkb )
		{
		  pa[i] = PORT_A;
		}
	      
	      clkb = pa[i] & 0x80;

	      //pa[i] = PORT_A;
	      pb[i] = PORT_B;
	      pc[i] = PORT_C;
	      
	    }
#endif
#if 1
	  for(i=0;i<NUM_SAMPLES;i++)
	    {
	      pa[i] = PORT_A;
	      pb[i] = PORT_B;
	      pc[i] = PORT_C;
	    }
#endif


	  
	  
	  for(i=0;i<NUM_SAMPLES;i++)
	    {
	      Serial.print("A:");
	      Serial.print(pa[i], HEX);
	      Serial.print(" B:");
	      Serial.print(pb[i], HEX);
	      Serial.print(" C:");
	      Serial.println(pc[i], HEX);
	    }
	  
	  break;
	}
    }
  
}

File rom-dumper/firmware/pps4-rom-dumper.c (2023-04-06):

////////////////////////////////////////////////////////////////////////////////
//
// PPS4 ROM Reader
//
// Reads A05 type PPS4/2 ROMs. These are -17V supply ROMs
// with data clocked out by a two phse clock arrangement. ROM and
// RAM memory spaces exist and the ROM can be mask programmed to respond
// to either memory space. It can also respond to any of the AS select lines
// which are effectively extra address lines. So, dump the entire space
// and work out where the data is later.
// ROM data is 8 bits and RAM data is 4 bits. RAM data can be addressed
// using the A11X signal as an upper/lower nibble select, so RAM data
// needs a slightly different addressing mode.
// 
//
// A startup option allows configuration data to be set up.
// At the top of flash memory we have two areas. One holds config
// data and one holds slots for ROM dumps. The tool only works with up to
// 16K ROMs so we have 16K slots. Slots are only ever filled by the dump code
// once full the slot have to be deleted with a flash sector erase.
//
////////////////////////////////////////////////////////////////////////////////

#include <ctype.h>
#include <stdio.h>
#include <string.h>
#include <stdlib.h>
#include <time.h>
#include "pico/stdlib.h"

//##include "hardware/pio.h"
//##include "hardware/clocks.h"

#include "hardware/flash.h"

// Use this if breakpoints don't work
#define DEBUG_STOP {volatile int x = 1; while(x) {} }

////////////////////////////////////////////////////////////////////////////////
//
//

// Only scan once, if multiple dumps needed then use a loop around the entire tool
// This makes the post processing easier.

#define NUM_SCANS    1
// 16 AS areas or 1024 bytes, A11X 2 areas and RAM and ROM data
#define SLOT_SIZE    (16*1024*2*2)

// How many slots there are. We could have very many slots, why not?
#define NUM_SLOTS    4

//-----------------------------------------------------------------------------

// Config sector
#define FLASH_CONFIG_OFFSET (1024 * 1024)
uint8_t *flash_config_contents = (uint8_t *) (XIP_BASE + FLASH_CONFIG_OFFSET);

// ROM image slots
#define FLASH_SLOT_OFFSET (1028 * 1024)
uint8_t *flash_slot_contents   = (uint8_t *) (XIP_BASE + FLASH_SLOT_OFFSET);


//--------------------------------------------------------------------------------

typedef enum
  {
   USB_DUMP = 0,
   SLOT_DUMP,
   NUM_SETUP_MODES,
  } SETUP_MODE;

char *setup_mode_name[NUM_SETUP_MODES] =
  {
   "USB DUMP",
   "SLOT_DUMP",
  };

typedef struct {
  int valid_a;     // magic number and an 
  int valid_b;     // inverterted magic number
  int mode;        // Mode we are in
  int usb_dump_count;   // Incremented after every dump
  int slot_dump_count;  // Incremented after every slot dump
} CONFIG_RECORD;

CONFIG_RECORD *config_record = (CONFIG_RECORD *) (XIP_BASE + FLASH_CONFIG_OFFSET);
CONFIG_RECORD copy_config_record;

#define CONFIG_MAGIC_A 0xCFAA0134
#define CONFIG_MAGIC_B 0xCFBB5623

// RAM slot which we copy to flash once filled
uint8_t slot_data[SLOT_SIZE];

//--------------------------------------------------------------------------------

void dump_slot(int slotnum);
void display_slot_map(void);
void clear_slot_data(void);

//------------------------------------------------------------------------------

const int LED_PIN = 25;

// This pin layout gives a rotation to the data
// rather than do more dumps, I'll live with it and post process

const int ID1_PIN = 0;
const int ID2_PIN = 1;
const int ID3_PIN = 2;
const int ID4_PIN = 3;
const int ID5_PIN = 4;
const int ID6_PIN = 5;
const int ID7_PIN = 6;
const int ID8_PIN = 7;

//
// The address lines (always inputs)
//
const int  AB1_PIN    =  8;
const int  AB2_PIN    =  9;
const int  AB3_PIN    = 10;
const int  AB4_PIN    = 11;
const int  AB5_PIN    = 12;
const int  AB6_PIN    = 13;
const int  AB7_PIN    = 14;
const int  AB8_PIN    = 15;
const int  AB9_PIN    = 16;
const int  AB10_PIN   = 17;
const int  AB11X_PIN  = 18;

const int  CLKA_PIN    = 19;
const int  CLKB_PIN    = 20;

const int  AS0_PIN    = 21;
const int  AS1_PIN    = 22;
const int  AS2_PIN    = 26;
const int  AS3_PIN    = 27;

// Arrays for setting GPIOs up
#define NUM_ADDR 11
#define NUM_AS   4
#define NUM_DATA 8

const int address_pins[NUM_ADDR] =
  {
   AB1_PIN,
   AB2_PIN,
   AB3_PIN,
   AB4_PIN,
   AB5_PIN,
   AB6_PIN,
   AB7_PIN,
   AB8_PIN,
   AB9_PIN,
   AB10_PIN,
   AB11X_PIN,
  };

const int as_pins[NUM_ADDR] =
  {
   AS0_PIN,
   AS1_PIN,
   AS2_PIN,
   AS3_PIN,
  };

const int data_pins[NUM_DATA] =
  {
   ID1_PIN,
   ID2_PIN,
   ID3_PIN,
   ID4_PIN,
   ID5_PIN,
   ID6_PIN,
   ID7_PIN,
   ID8_PIN,
  };

////////////////////////////////////////////////////////////////////////////////
//
// Set the address lines to a value
//
////////////////////////////////////////////////////////////////////////////////

void set_address(int addr)
{
  for(int i=0; i<NUM_ADDR; i++)
    {
      if( addr & (1<<i) )
	{
	  gpio_put(address_pins[i], 1);
	}
      else
	{
	  gpio_put(address_pins[i], 0);
	}
    }
}

void set_as(int as)
{
  for(int i=0; i<NUM_AS; i++)
    {
      if( as & (1<<i) )
	{
	  gpio_put(as_pins[i], 1);
	}
      else
	{
	  gpio_put(as_pins[i], 0);
	}
    }
}


int read_data(void)
{
  int result = 0;
  
  for(int i=0; i<NUM_DATA; i++)
    {
      if( gpio_get(data_pins[i]) )
	{
	  result |= (1 << i);
	}
    }
  return(result);
}

////////////////////////////////////////////////////////////////////////////////


void print_hex(uint8_t *buf, int len)
{
  for (size_t i = 0; i < len; ++i)
    {
      if((i % 16) == 0)
	{
	  printf("\n");
	}
      
      printf("%02x ", buf[i]);
    }
}

////////////////////////////////////////////////////////////////////////////////

void prompt(void)
{
  printf("\n>");
}

void setup_menu(void)
{
  printf("\nSetup");
  printf("\n=====");
  printf("\n");
  printf("\n?: Display menu");
  printf("\nq: Quit");
  printf("\nc: Clear config settings");
  printf("\nC: Clear slot data");
  printf("\nd: Display config settings");
  printf("\np: Print information");
  printf("\nP: Dump config sector");
  printf("\nU: Set USB dump mode");
  printf("\nS: Set slot dump mode");
  printf("\nM: Display slot map");
  printf("\nr: Display slot");
  printf("\nz: Zero USB dump count");
  printf("\nZ: Zero Slot dump count");
}

void erase_config_sector(void)
{
  flash_range_erase(FLASH_CONFIG_OFFSET, FLASH_SECTOR_SIZE);
}

void erase_slot_data(void)
{
  flash_range_erase(FLASH_SLOT_OFFSET, SLOT_SIZE*NUM_SLOTS);
}

void program_config_record(CONFIG_RECORD *data)
{
  flash_range_program(FLASH_CONFIG_OFFSET,(uint8_t *) data, sizeof(CONFIG_RECORD));
}

void write_config_record(CONFIG_RECORD *cfg_rec)
{
  // Make record valid
  cfg_rec->valid_a = CONFIG_MAGIC_A;
  cfg_rec->valid_b = CONFIG_MAGIC_B;
  
  erase_config_sector();
  program_config_record(cfg_rec);
}

void zero_usb_dump_count(void)
{
  copy_config_record = *config_record;
  copy_config_record.usb_dump_count = 0;
  write_config_record(&copy_config_record);
}
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

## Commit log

2020-10-26 Moved files about
    [ppstrace1.kicad_pcb, ppstrace1.sch]
2020-12-05 Added traces
2020-12-08 Added more traces, some broken. Trace processing script now decodes successfully after fixes to input processing.
    [ppstrace1.sch, rockwell_920-3.kicad_pcb, rockwell_920-3.sch]
2020-12-11 Added traces taken from reset after a certain number of clock cycles.
2020-12-24 More annotated listing. More data from capture runs
    [rockwell920.kicad_pcb, rockwell920.sch]
2021-03-12 Updated annotated ROM file
    [rockwell920.sch]
